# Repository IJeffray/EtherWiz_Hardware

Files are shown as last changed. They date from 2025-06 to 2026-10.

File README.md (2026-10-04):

# "EtherWiz" Acorn Ethernet podule (WizNet W6100)

October 2026

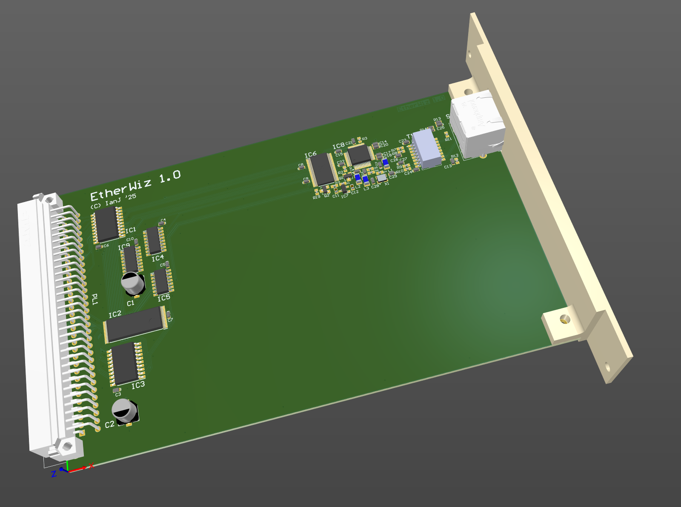
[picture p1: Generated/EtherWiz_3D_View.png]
3D View


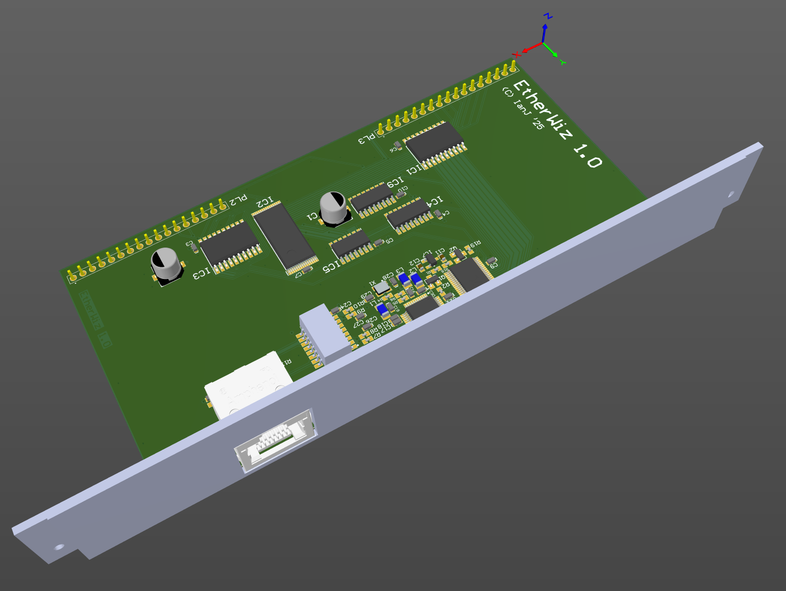
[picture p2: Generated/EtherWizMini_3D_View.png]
3D View


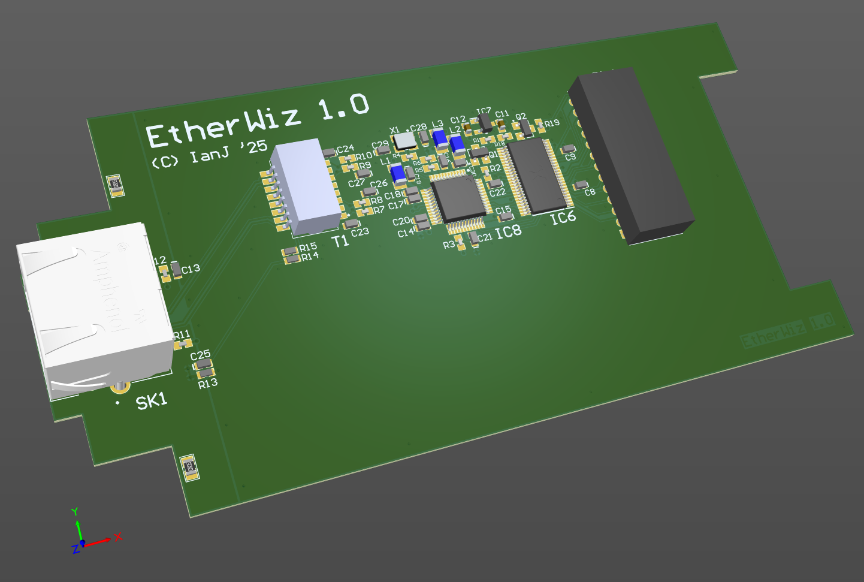
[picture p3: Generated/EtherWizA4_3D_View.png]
3D View


A work in progress hardware design for an Ethernet card using the WizNet W6100 device in MACRAW mode.  No 'legacy' components - everything is available as new/active hardware.   There's 512K flash on board rather than a podule ROM - the flash can be updated from RISC OS.

The first spin board works, with bodges, which have been worked in to the updated design which has not yet been validated.  The updated design has also been laid out as a minipodule, which has been validated.   The A4 version design also works, with a gate inversion bodge which has also now been laid out.

Interrupt latching has now been implemented but not yet been tested.

The design for the 3D-printable backplates are included.

All RISC OS code (EtherWiz DCI4 Ethernet driver, podule binder, flashing code) is all my own work, written from scratch in BASIC assembler, OpenSource, and is available in the EtherWiz_Software repo.

## Licence

No warranty is provided, and this work is used at your own risk.  

Licenced as CC BY-SA 4.0

Copyright 2025-26 Ian Jeffray

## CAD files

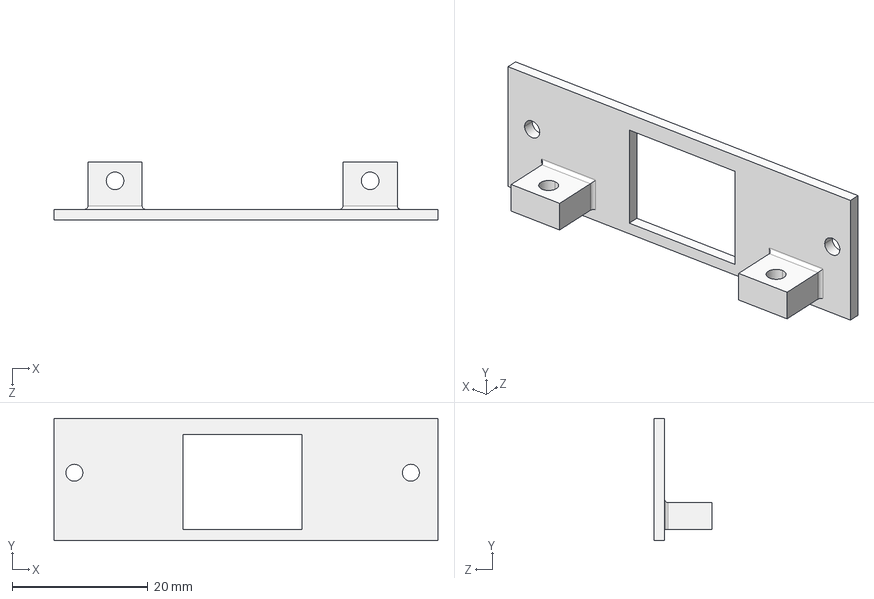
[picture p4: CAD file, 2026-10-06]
Backplate/EtherWizRiscPC7kBackplate.STEP
56.6 x 18.0 x 8.60 mm

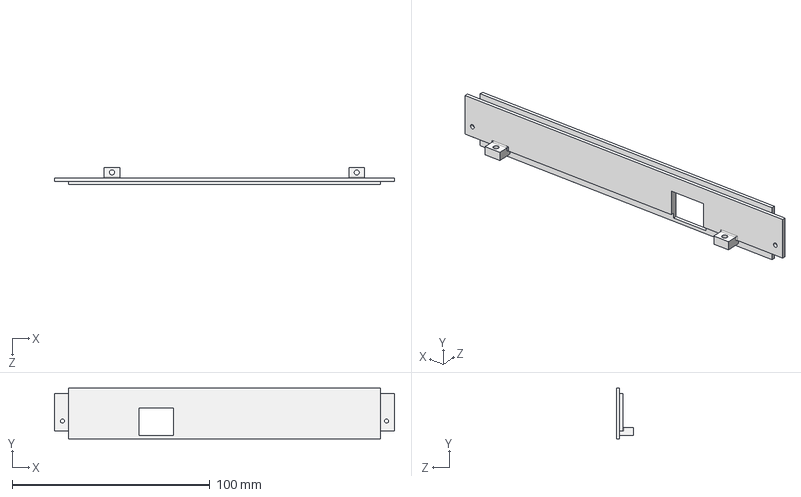
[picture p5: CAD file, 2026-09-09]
Backplate/EtherWizMini_Backplate.STEP
172.0 x 25.6 x 8.60 mm

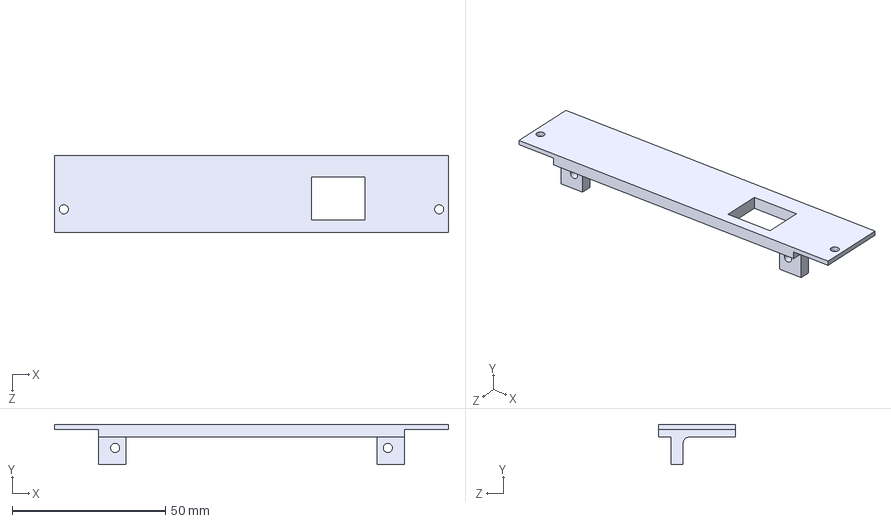
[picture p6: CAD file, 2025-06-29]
Backplate/EtherWiz_Backplate.STEP
128.6 x 13.1 x 25.0 mm

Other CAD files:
Backplate/EtherWizMini_Backplate.SLDPRT
Backplate/EtherWizRiscPC7kBackplate.SLDPRT
Backplate/EtherWiz_Backplate.SLDPRT

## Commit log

2025-06-20 Initial rough commit - ROM interface, level shifting, Wiznet, power supply, magnetics and RJ45.
    [Acorn.PcbLib, Acorn.SchLib, EtherWiz.PrjPcb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]
2025-06-21 Dump the DIP EPROM, add SMT flash
    [EtherWiz.SchDoc]
2025-06-28 Rejig the flash
    [EtherWiz.PrjPcb, EtherWiz.SchDoc]
2025-06-29 Layout tweaks. New LDO.
    [EtherWiz.SchDoc]
2025-06-29 Add backplate 3D printable model
    [EtherWiz_Backplate.SLDPRT, EtherWiz_Backplate.STEP]
2025-07-09 Add missed 3v3 CT on magnetics. Add 2nd NPN for PIRQ as it was inverting. Add additional decoding for 3v3 level translator direction so that it only goes in to 'read' mode when really reading the Wiz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
    [EtherWiz.PrjPcb, EtherWiz.SchDoc]
2025-07-20 Added minipodule layout
    [EtherWiz.PrjPcb, EtherWiz.SchDoc]
2025-07-21 Tweak mini PCB size/layout and create 3D printable backplate
    [EtherWizMini_Backplate.SLDPRT, EtherWizMini_Backplate.STEP]
2025-07-25 Tweak board output job for mini board
2025-08-08 Add A4 variant - no flash (can't be supported). Incomplete as yet.
    [EtherWiz.PrjPcb, EtherWiz.SchDoc]
2025-08-08 Further A4 version improvements - very simple now.
    [EtherWiz.SchDoc]
2025-08-09 Add A4 output job
    [EtherWiz.PrjPcb, EtherWiz.SchDoc, EtherWizA4.PcbDoc]
2025-08-20 Change ferrite bead - original part no longer manufactured
    [EtherWiz.SchDoc, EtherWizA4.PcbDoc]
2025-08-20 More NF caps on A4 version
    [EtherWiz.SchDoc, EtherWizA4.PcbDoc]
2025-09-03 Similar buffer error on A4 build to the original - can't use PR/W directly to set the buffer direction, so add a NOT gate and use /PRE instead.
    [EtherWiz.PrjPcb, EtherWiz.SchDoc, EtherWizA4.PcbDoc]
2025-12-27 Split schematic to two sheets - one just the host-side sockets. Add A3020/A4000 variant but noted lack of address lines. Tweak A4 variant to use lower profile RJ45 (no LEDs)
    [EtherWiz.PrjPcb, EtherWiz.SchDoc, EtherWiz3K4KNic.PcbDoc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]
2026-07-15 Add podule manager interrupt data bit. Split to more schematic sheets & tidy. Rough-out RiscPC/A7000 NIC version.
    [EtherWiz.PcbDoc, EtherWiz.PrjPcb, EtherWiz.SchDoc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]
2026-09-09 Chunkier mounting bosses so folks don't snap them so easily
    [EtherWizMini_Backplate.SLDPRT, EtherWizMini_Backplate.STEP]
2026-10-04 Add address and control line buffering to be a good citizen
    [EtherWiz.PcbDoc, EtherWiz.PrjPcb, EtherWiz.SchDoc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]
2026-10-04 Annotation tweaks
    [EtherWiz.PcbDoc, EtherWizMini.PcbDoc]
2026-10-04 More schematic chop-up and created separate projects for each PCB variant to better handle the differences. Full layout on the RiscPC NIC done, including PLCC flash for offboard programming as the NI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
    [EtherWiz.PcbDoc, EtherWiz.PrjPcb, EtherWiz.SchDoc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]
2026-10-06 RiscPC backplate doesn't actually quite fit when made to Acorn's spec, so shave a wee bit off. Duh.
    [EtherWizRiscPC7kBackplate.SLDPRT, EtherWizRiscPC7kBackplate.STEP]
2026-10-06 Correct output job file and add to each of the newly split projects. Add AND gate to RiscPC NIC so that there's possibility of doing a flasher.
    [EtherWiz_3K4KNic.PrjPcb, EtherWiz_A4.PrjPcb, EtherWiz_FullSize.PrjPcb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]
